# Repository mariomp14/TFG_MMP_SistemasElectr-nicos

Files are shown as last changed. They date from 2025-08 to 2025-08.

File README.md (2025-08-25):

# TFG_MMP_SistemasElectrónicos
Este repositorio fue creado como complemento de mi TFG para compartir:

### 1. **Firmware/**
Contiene el código fuente desarrollado:
- Programas escritos en C/C++.  
- Configuraciones y bibliotecas necesarias (CMake, scripts, etc.).

### 2. **PCBs/**
Incluye todos los archivos relacionados con el diseño y fabricación de la placa:
- `esquemas/`: diagramas eléctricos en formato `.sch` (KiCad).
- `diseño/`: los diseños en `.kicad_pcb`, `.pro`, `.kicad_sch`.
- `gerbers/`: los archivos estándares para fabricación.
- `pick_and_place/`: archivos `.csv` o `.pos` con coordenadas de colocación de componentes.

---

##  ¿Cómo usar este repositorio?

1. **Firmware**:
   - Clona el repositorio.
   - Ingresa al directorio `Firmware`.
   - Entiende el código y utilizalo en tu microcontrolador de Espressif!

2. **PCBs**:
   - Abre el diseño en KiCad.
   - Revisa esquemáticos y layout.
   - Si deseas fabricar, usa los Gerbers y el archivo de taladrado.

---

##  Contribuye

¿Quieres colaborar o revisar el proyecto?  
— Si deseas utilizar algún recurso, contrinuir mejoras o discutir ideas, **abre un issue** o envía un **Pull Request**. ¡Toda ayuda es bien recibida!

---

¡Gracias por explorar mi trabajo!  
— Mario (mariomp14)

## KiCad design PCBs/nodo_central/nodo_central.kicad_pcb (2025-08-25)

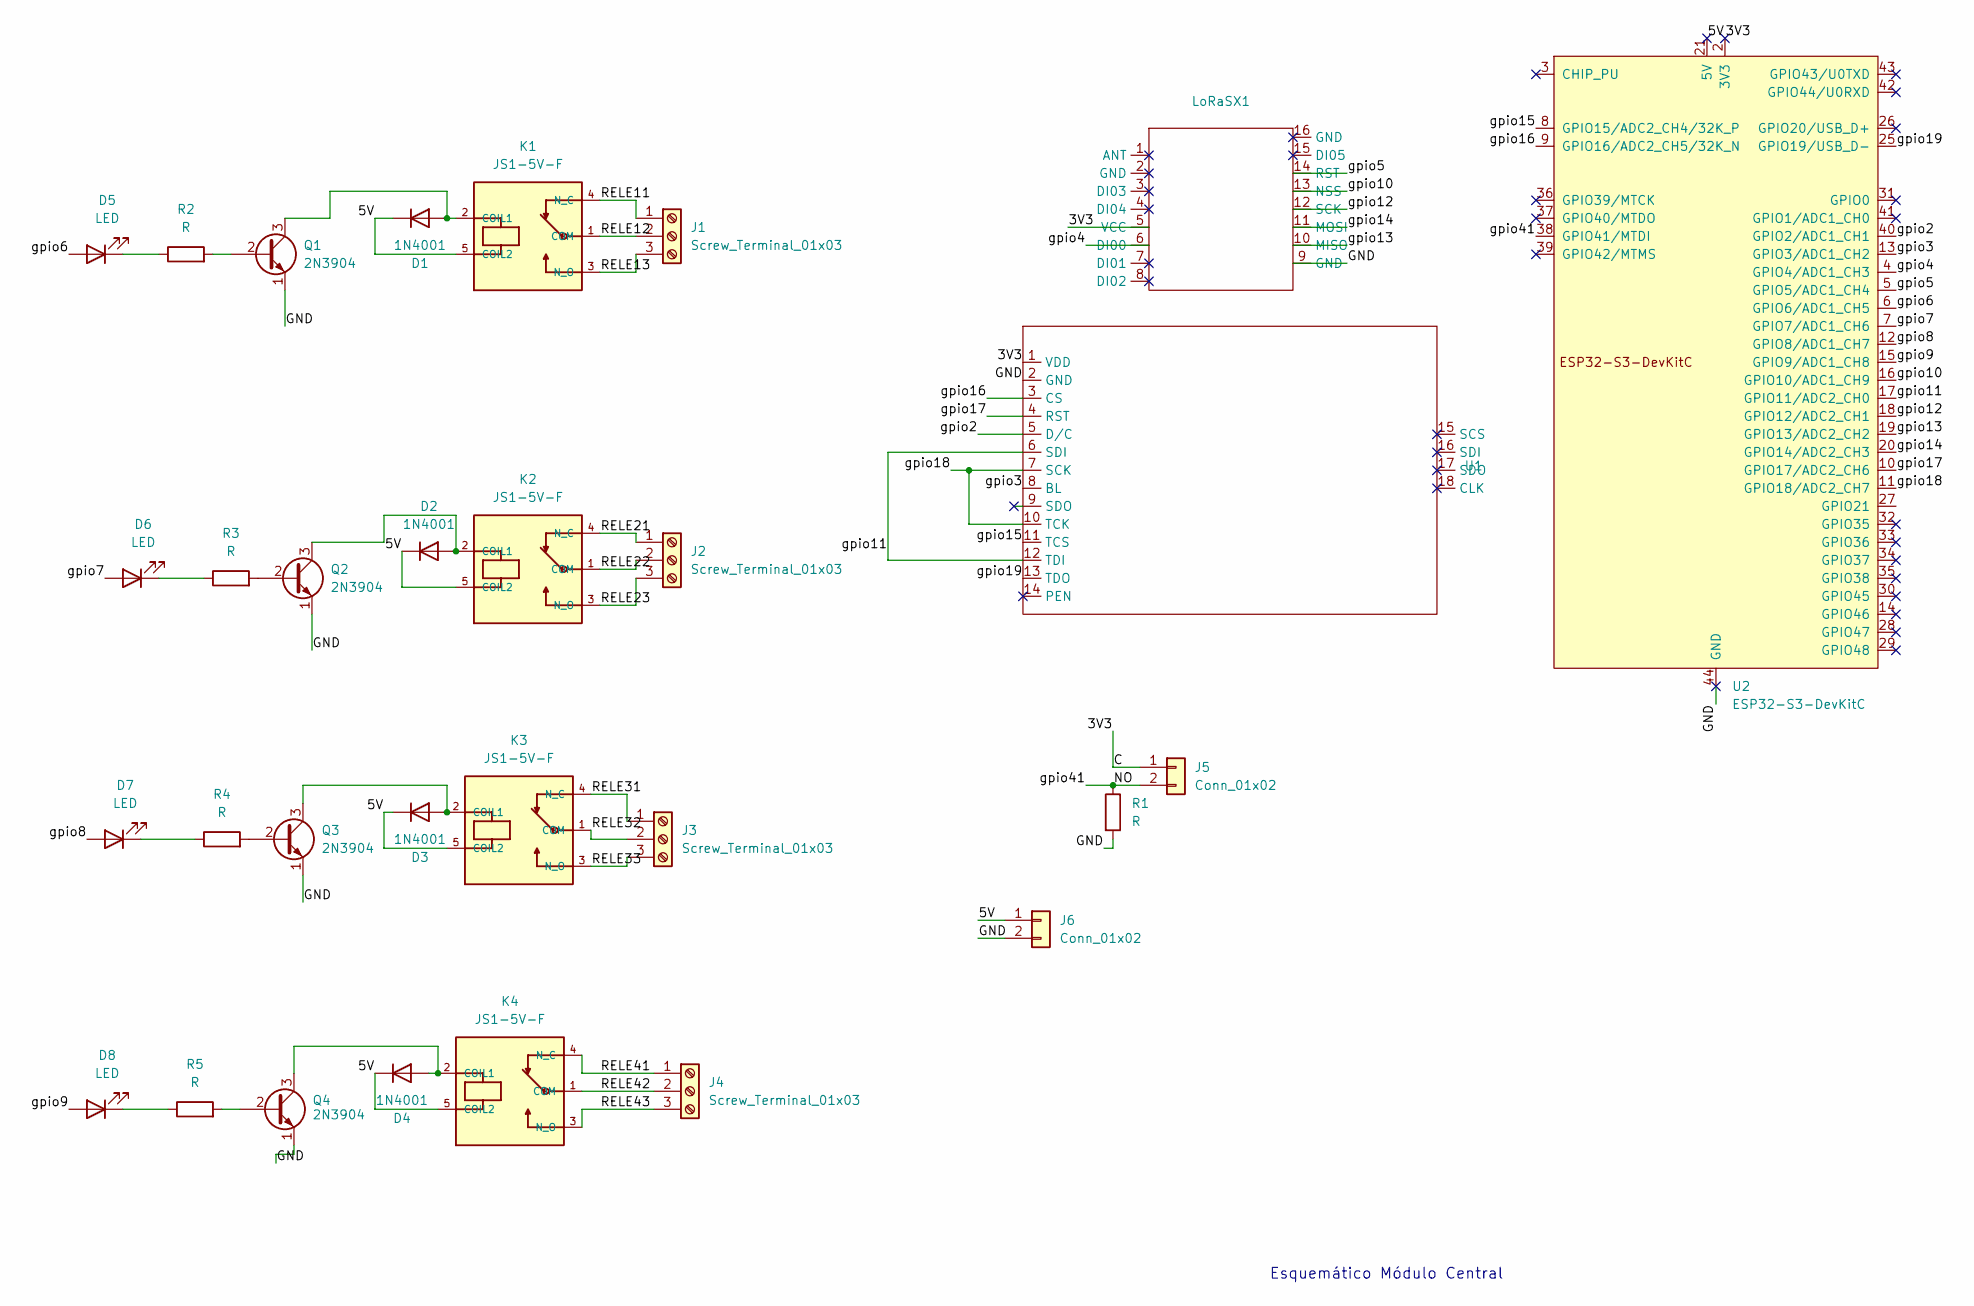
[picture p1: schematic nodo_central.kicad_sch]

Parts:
D1, D2, D3, D4: 1N4001; D_DO-41_SOD81_P10.16mm_Horizontal
D5, D6, D7, D8: LED; LED_D5.0mm
J1, J2, J3, J4: Screw_Terminal_01x03; TerminalBlock_bornier-3_P5.08mm
J5, J6: Conn_01x02; PinHeader_1x02_P2.54mm_Vertical
K1, K2, K3, K4: JS1-5V-F; RELAY_JS1-5V-F; PARTREV N/A
LoRaSX1: XCVR_RFM95W-868S2
Q1, Q2, Q3, Q4: 2N3904; TO-92_Inline_Wide
R1, R2, R3, R4, R5: R; R_Axial_DIN0207_L6.3mm_D2.5mm_P7.62mm_Horizontal
U1: ILI9488
U2: ESP32-S3-DevKitC

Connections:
/3V3: J5.1, LoRaSX1.5 (VCC), U1.1 (VDD), U2.1 (3V3), U2.2 (3V3)
/5V: D1.1 (K), D2.1 (K), D3.1 (K), D4.1 (K), J6.1, K1.5 (COIL2), K2.5 (COIL2), K3.5 (COIL2), K4.5 (COIL2), U2.21 (5V)
/GND: J6.2, LoRaSX1.9 (GND), Q1.1 (E), Q2.1 (E), Q3.1 (E), Q4.1 (E), R1.2, U1.2 (GND), U2.22 (GND), U2.23 (GND), U2.24 (GND), U2.44 (GND)
/NO: J5.2, R1.1, U2.38 (GPIO41/MTDI)
/RELE11: J1.1, K1.4 (N_C)
/RELE12: J1.2, K1.1 (COM)
/RELE13: J1.3, K1.3 (N_O)
/RELE21: J2.1, K2.4 (N_C)
/RELE22: J2.2, K2.1 (COM)
/RELE23: J2.3, K2.3 (N_O)
/RELE31: J3.1, K3.4 (N_C)
/RELE32: J3.2, K3.1 (COM)
/RELE33: J3.3, K3.3 (N_O)
/RELE41: J4.1, K4.4 (N_C)
/RELE42: J4.2, K4.1 (COM)
/RELE43: J4.3, K4.3 (N_O)
/gpio2: U1.5 (D/C), U2.40 (GPIO2/ADC1_CH1)
/gpio3: U1.8 (BL), U2.13 (GPIO3/ADC1_CH2)
/gpio4: LoRaSX1.6 (DI00), U2.4 (GPIO4/ADC1_CH3)
/gpio5: LoRaSX1.14 (RST), U2.5 (GPIO5/ADC1_CH4)
/gpio6: D5.2 (A), U2.6 (GPIO6/ADC1_CH5)
/gpio7: D6.2 (A), U2.7 (GPIO7/ADC1_CH6)
/gpio8: D7.2 (A), U2.12 (GPIO8/ADC1_CH7)
/gpio9: D8.2 (A), U2.15 (GPIO9/ADC1_CH8)
/gpio10: LoRaSX1.13 (NSS), U2.16 (GPIO10/ADC1_CH9)
/gpio11: U1.6 (SDI), U1.12 (TDI), U2.17 (GPIO11/ADC2_CH0)
/gpio12: LoRaSX1.12 (SCK), U2.18 (GPIO12/ADC2_CH1)
/gpio13: LoRaSX1.10 (MISO), U2.19 (GPIO13/ADC2_CH2)
/gpio14: LoRaSX1.11 (MOSI), U2.20 (GPIO14/ADC2_CH3)
/gpio15: U1.11 (TCS), U2.8 (GPIO15/ADC2_CH4/32K_P)
/gpio16: U1.3 (CS), U2.9 (GPIO16/ADC2_CH5/32K_N)
/gpio17: U1.4 (RST), U2.10 (GPIO17/ADC2_CH6)
/gpio18: U1.7 (SCK), U1.10 (TCK), U2.11 (GPIO18/ADC2_CH7)
/gpio19: U1.13 (TDO), U2.25 (GPIO19/USB_D-)
unnamed: D1.2 (A), K1.2 (COIL1), Q1.3 (C)
unnamed: D2.2 (A), K2.2 (COIL1), Q2.3 (C)
unnamed: D3.2 (A), K3.2 (COIL1), Q3.3 (C)
unnamed: D4.2 (A), K4.2 (COIL1), Q4.3 (C)
unnamed: D5.1 (K), R2.1
unnamed: D6.1 (K), R3.1
unnamed: D7.1 (K), R4.1
unnamed: D8.1 (K), R5.1
unnamed: Q1.2 (B), R2.2
unnamed: Q2.2 (B), R3.2
unnamed: Q3.2 (B), R4.2
unnamed: Q4.2 (B), R5.2

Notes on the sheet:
Esquemático Módulo Central

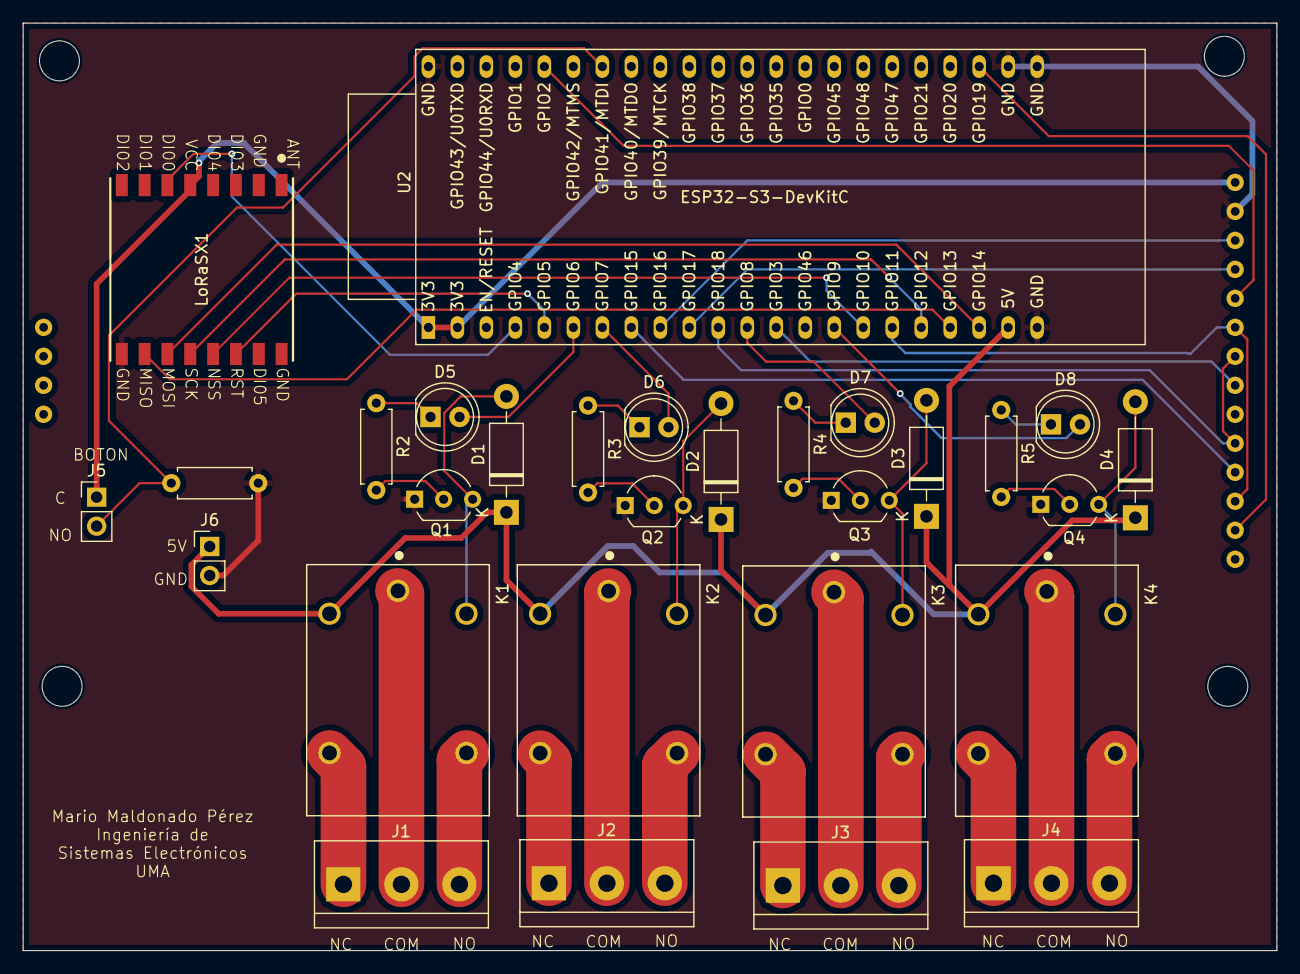
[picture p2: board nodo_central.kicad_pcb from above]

Board: 2 copper layers, 109.8 x 81.3 mm, 30 parts (1 on the bottom side), 46 nets.

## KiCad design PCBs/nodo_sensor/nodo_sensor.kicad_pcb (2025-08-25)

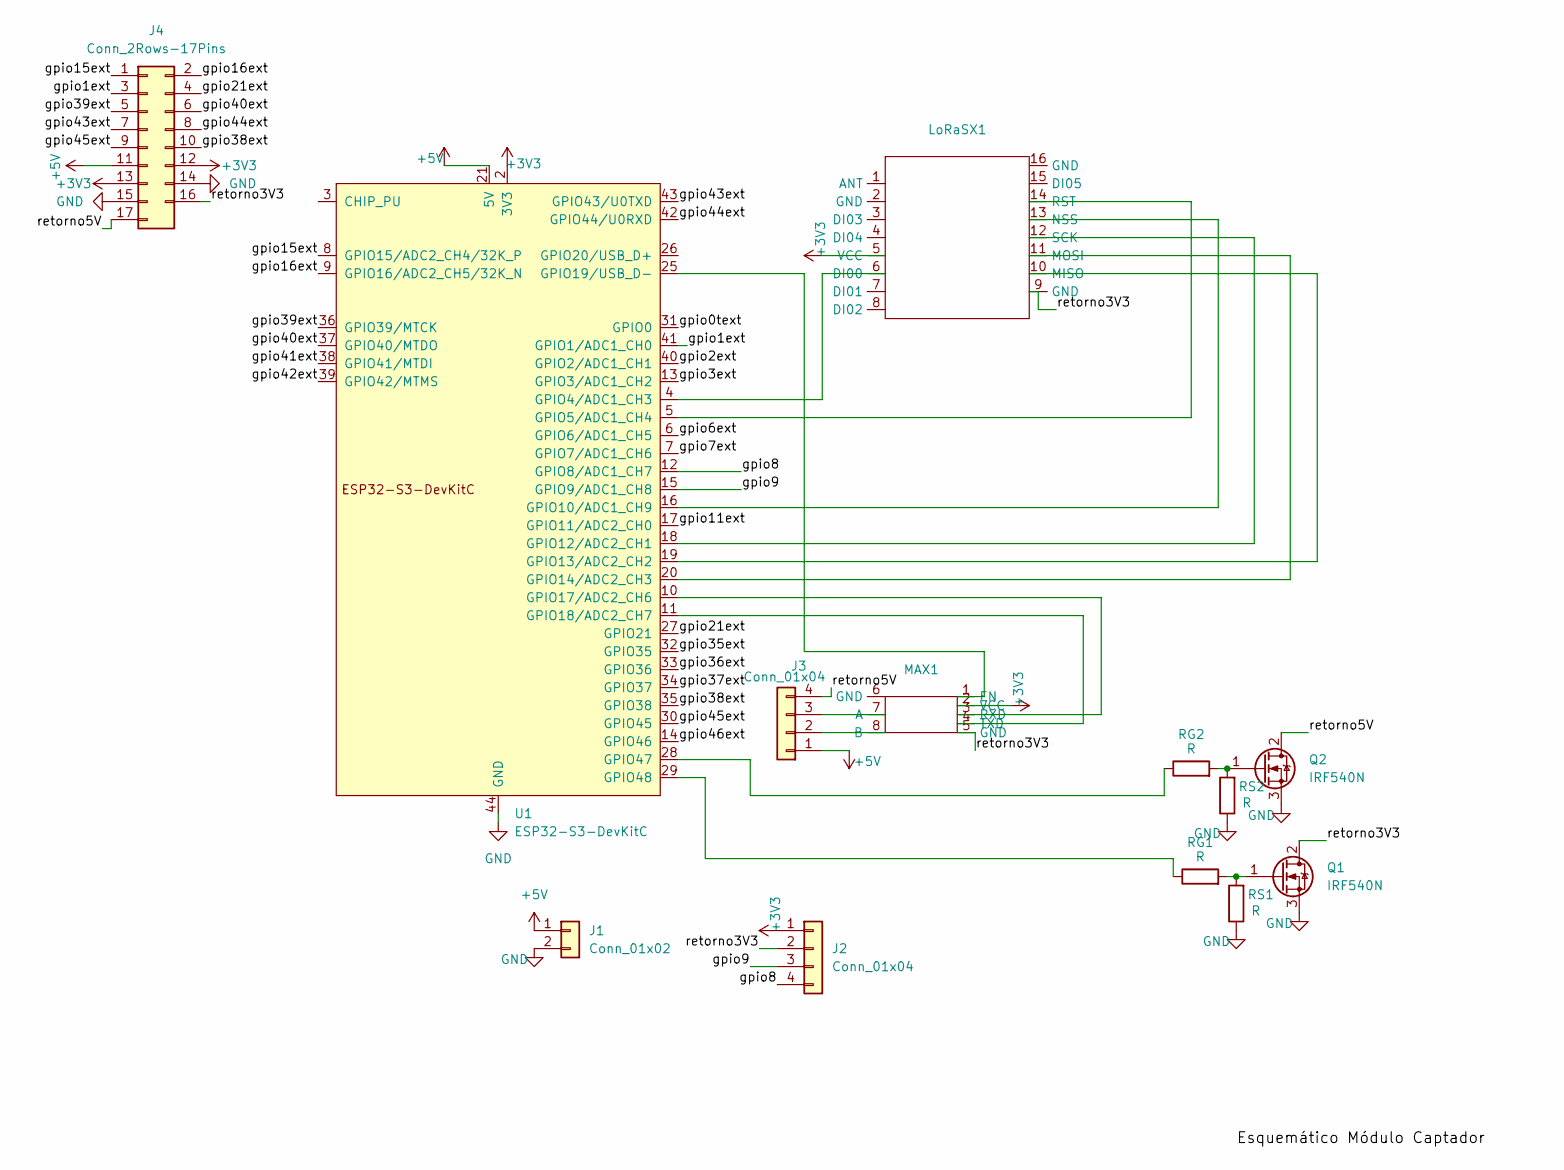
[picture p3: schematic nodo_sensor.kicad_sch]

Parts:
J1: Conn_01x02; PinHeader_1x02_P2.54mm_Vertical
J2: Conn_01x04; PinHeader_1x04_P2.54mm_Vertical_Humedad
J3: Conn_01x04; PinHeader_1x04_P2.54mm_Vertical_Suelo
J4: Conn_2Rows-17Pins; PinHeader_2x09_P2.54mm_Vertical
LoRaSX1: XCVR_RFM95W-868S2
MAX1: MAX3485
Q1, Q2: IRF540N; TO-220-3_Vertical
RG1, RG2: R; R_Axial_DIN0207_L6.3mm_D2.5mm_P7.62mm_Horizontal
RS1, RS2: R; R_Axial_DIN0207_L6.3mm_D2.5mm_P7.62mm_Horizontal
U1: ESP32-S3-DevKitC

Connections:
+3V3: J2.1, J4.12, J4.13, LoRaSX1.5 (VCC), MAX1.2 (VCC), U1.1 (3V3), U1.2 (3V3)
+5V: J1.1, J3.1, J4.11, U1.21 (5V)
/gpio0text: U1.31 (GPIO0)
/gpio1ext: J4.3, U1.41 (GPIO1/ADC1_CH0)
/gpio2ext: U1.40 (GPIO2/ADC1_CH1)
/gpio3ext: U1.13 (GPIO3/ADC1_CH2)
/gpio6ext: U1.6 (GPIO6/ADC1_CH5)
/gpio7ext: U1.7 (GPIO7/ADC1_CH6)
/gpio8: J2.4, U1.12 (GPIO8/ADC1_CH7)
/gpio9: J2.3, U1.15 (GPIO9/ADC1_CH8)
/gpio11ext: U1.17 (GPIO11/ADC2_CH0)
/gpio15ext: J4.1 (gpio15), U1.8 (GPIO15/ADC2_CH4/32K_P)
/gpio16ext: J4.2, U1.9 (GPIO16/ADC2_CH5/32K_N)
/gpio21ext: J4.4, U1.27 (GPIO21)
/gpio35ext: U1.32 (GPIO35)
/gpio36ext: U1.33 (GPIO36)
/gpio37ext: U1.34 (GPIO37)
/gpio38ext: J4.10, U1.35 (GPIO38)
/gpio39ext: J4.5, U1.36 (GPIO39/MTCK)
/gpio40ext: J4.6, U1.37 (GPIO40/MTDO)
/gpio41ext: U1.38 (GPIO41/MTDI)
/gpio42ext: U1.39 (GPIO42/MTMS)
/gpio43ext: J4.7, U1.43 (GPIO43/U0TXD)
/gpio44ext: J4.8, U1.42 (GPIO44/U0RXD)
/gpio45ext: J4.9, U1.30 (GPIO45)
/gpio46ext: U1.14 (GPIO46)
/retorno3V3: J2.2, J4.16, LoRaSX1.9 (GND), MAX1.5 (GND), Q1.2 (D)
/retorno5V: J3.4, J4.17, Q2.2 (D)
GND: J1.2, J4.14, J4.15, Q1.3 (S), Q2.3 (S), RS1.1, RS2.1, U1.22 (GND), U1.23 (GND), U1.24 (GND), U1.44 (GND)
unnamed: J3.2, MAX1.8 (B)
unnamed: J3.3, MAX1.7 (A)
unnamed: LoRaSX1.6 (DI00), U1.4 (GPIO4/ADC1_CH3)
unnamed: LoRaSX1.10 (MISO), U1.19 (GPIO13/ADC2_CH2)
unnamed: LoRaSX1.11 (MOSI), U1.20 (GPIO14/ADC2_CH3)
unnamed: LoRaSX1.13 (NSS), U1.16 (GPIO10/ADC1_CH9)
unnamed: LoRaSX1.14 (RST), U1.5 (GPIO5/ADC1_CH4)
unnamed: LoRaSX1.12 (SCK), U1.18 (GPIO12/ADC2_CH1)
unnamed: MAX1.1 (EN), U1.25 (GPIO19/USB_D-)
unnamed: MAX1.3 (RXD), U1.10 (GPIO17/ADC2_CH6)
unnamed: MAX1.4 (TXD), U1.11 (GPIO18/ADC2_CH7)
unnamed: Q1.1 (G), RG1.2, RS1.2
unnamed: Q2.1 (G), RG2.2, RS2.2
unnamed: RG2.1, U1.28 (GPIO47)
unnamed: RG1.1, U1.29 (GPIO48)

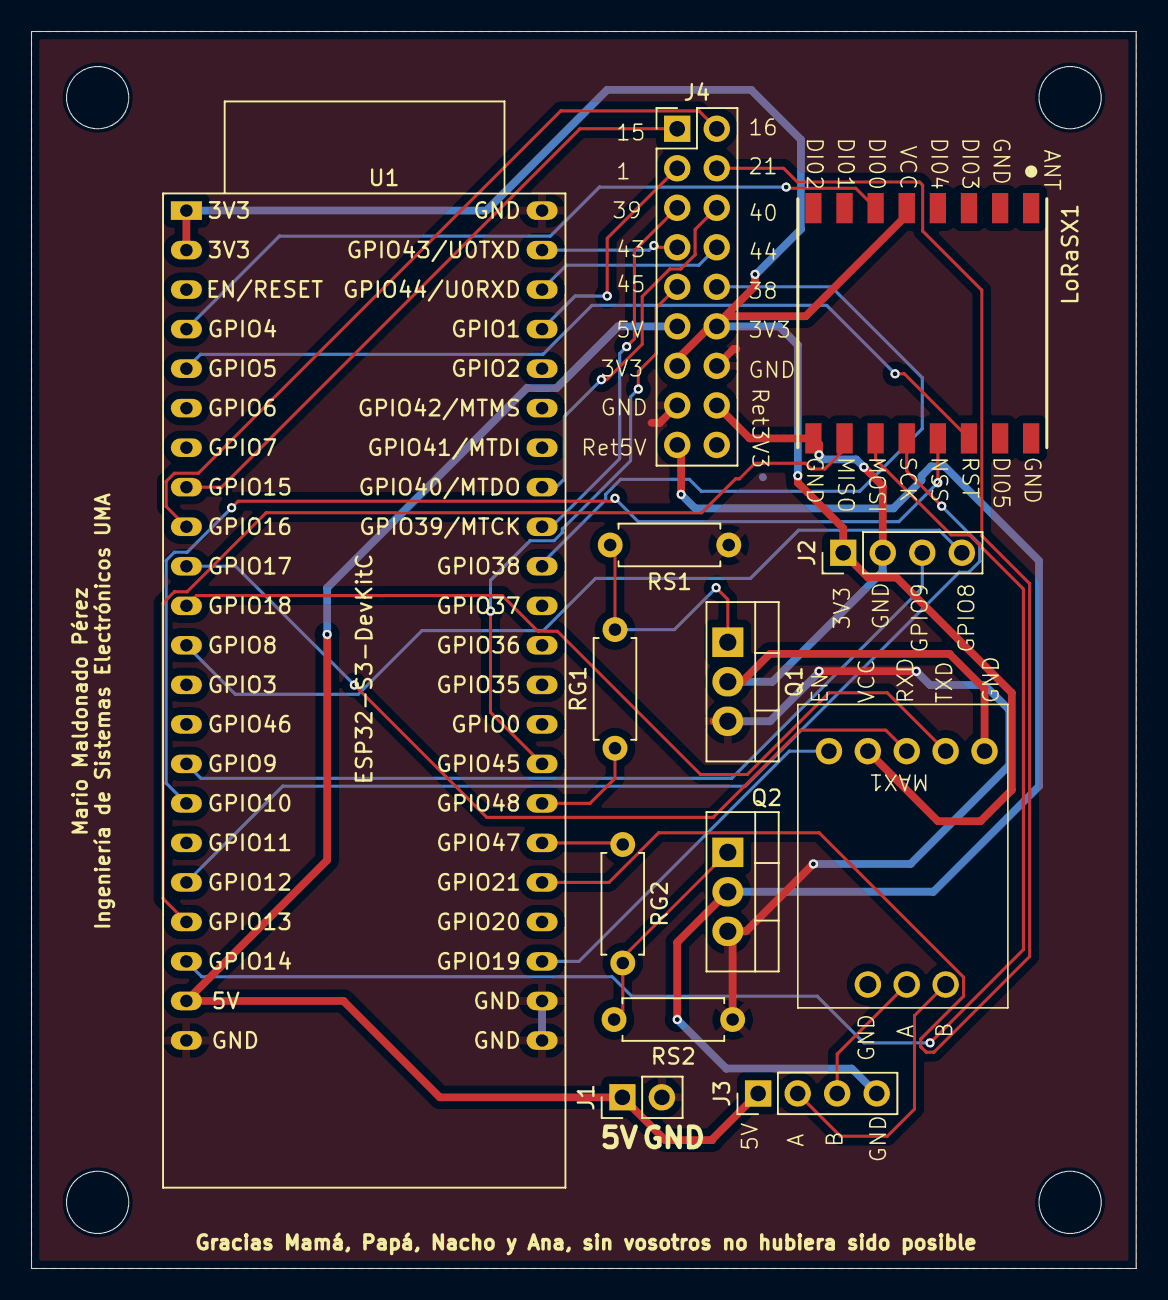
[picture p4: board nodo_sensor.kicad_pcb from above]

Board: 2 copper layers, 71.0 x 79.5 mm, 13 parts (0 on the bottom side), 32 nets.

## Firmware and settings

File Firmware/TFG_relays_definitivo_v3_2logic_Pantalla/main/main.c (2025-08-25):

#include "LoRa.h"
#include "esp_netif.h"
#include "freertos/FreeRTOSConfig.h"
#include "freertos/portmacro.h"
#include "sht40.h"
#include "driver/gpio.h"
#include "esp_err.h"
//#include "freertos/projdefs.h"
#include "hal/gpio_types.h"
#include <stdint.h>
#include <stdio.h>
#include <stdbool.h>
#include <string.h>
#include <unistd.h>

#include "freertos/FreeRTOS.h"
#include "freertos/task.h"
#include "esp_log.h"
#include "string.h"
#include "freertos/timers.h"
#include "esp_sleep.h"

#include "nvs_flash.h"
#include "mqtt_client.h"
#include "my_mqtt/include/my_mqtt.h"
#include "my_wifi/include/my_wifi.h"

#include "screen.h"
#include "ui.h"
#include <math.h>  // Para la función exp()

static const char *TAG = "LoRa_App";
static void safe_update_labels(void *param);
 
#define RELAY_1 GPIO_NUM_6
#define RELAY_2 GPIO_NUM_7
#define RELAY_3 GPIO_NUM_8
#define RELAY_4 GPIO_NUM_9
//Mecanismos de freeRTOS
static TaskHandle_t manejador_tarea_relays = NULL; 
static TaskHandle_t manejador_tarea_receiver = NULL; 
static QueueHandle_t lora_queue;  // Cola para almacenar los mensajes LoRa
static QueueHandle_t myQueueSet;
static SemaphoreHandle_t lora_semaphore;  // Semáforo para manejar la interrupción
static SemaphoreHandle_t security_semaphore_Sector1; 
static SemaphoreHandle_t security_semaphore_Sector2; 
SemaphoreHandle_t systemReadySemaphore;
TimerHandle_t timer_security_Sector1 = NULL; 
TimerHandle_t timer_security_Sector2 = NULL; 

QueueHandle_t cola_consignas;


RTC_DATA_ATTR volatile uint16_t light_sleep_time = 210;// 3 minutos y medio																																																
RTC_DATA_ATTR volatile uint32_t time_security_s = 180;
RTC_DATA_ATTR volatile uint16_t	convert_ms = 1000;

uint8_t MasterNode = 0xFF;//Nodo que controla la nebulización
uint8_t Node1 = 0xBB;
uint8_t Node2 = 0xAA;

#define BOTON_GPIO GPIO_NUM_41


//Funciones y tareas
static portTASK_FUNCTION(RELAYS, pvParameters);
static portTASK_FUNCTION(RECEIVER, pvParameters);
void configure_send_ack(uint8_t Node);
void setup_interrupt(void);
void procesar_buffer(uint8_t *buf);
static void  gpio_isr_handler(void *arg);
void CONSIGNMENTS(void *param);
uint8_t calcular_dpv(float temperatura, float humedad_relativa, uint8_t sector);
int automatismo_desactivado(void);
void actualizar_label_async(lv_obj_t *label, const char *nuevo_texto);
void inicializar_nvs_por_defecto();

 DatoLVGLtemporal temp_S1 = {0};  
 DatoLVGLtemporal hum_S1 = {0}; 
 DatoLVGLtemporal temp_S2 = {0}; 
 DatoLVGLtemporal hum_S2 = {0}; 
 DatoLVGLtemporal temp_suelo = {0}; 
 DatoLVGLtemporal hum_suelo = {0}; 
 DatoLVGLtemporal cond_suelo = {0}; 
 DatoLVGLtemporal ph_suelo = {0}; 
 DatoLVGLtemporal DPVS1 = {0};
 DatoLVGLtemporal DPVS2 = {0};
 DatoLVGLtemporal DPVminS1 = {0};
 DatoLVGLtemporal DPVminS2 = {0};
 DatoLVGLtemporal DPVmaxS1 = {0};
 DatoLVGLtemporal DPVmaxS2 = {0};
 DatoLVGLbooltemporal Rele1 = {0}; 
 DatoLVGLbooltemporal Rele2= {0}; 
 DatoLVGLbooltemporal estado_automatismo= {0}; 

void IRAM_ATTR boton_isr_handler(void* arg) {
    BaseType_t xHigherPriorityTaskWoken = pdFALSE;
    xSemaphoreGiveFromISR(semaforo_activar_timer_screen, &xHigherPriorityTaskWoken);
    if (xHigherPriorityTaskWoken) {
        portYIELD_FROM_ISR();
    }
}



void app_main(void)
{
	
	systemReadySemaphore = xSemaphoreCreateBinary();  // Crear el semáforo global
	
	//WIFI e MQTT//
	esp_log_level_set("wifi", ESP_LOG_VERBOSE);//Habilita los logs detallados de Wi-Fi para ver mensajes de error:
	 									//Poner un comando desde mqtt para eliminar la flash?
	//nvs_flash_erase(); 					//Solo para pruebas, eliminar?!->borra memoria NVS. Ojo si pongo esto no tendria sentido guardarlo en la memoria volátil no?
    ESP_ERROR_CHECK(nvs_flash_init());  //Se usa para guardar datos en memoria no volátil, como credenciales WiFi, configuraciones o tokens de acceso.
    inicializar_nvs_por_defecto();  // para guardar los valores de dpv max y min y si esta o no desactivado el automatismo
    esp_netif_init();					//inicializa la pila de red, para poder usar wifi
    esp_event_loop_create_default();	//crea e inicializa el bucle de eventos predeterminado en esp-idf (wifi,bluetooth...)
    wifi_connect_sta();
	

    ESP_LOGI("MAIN", "Esperando WiFi y MQTT...");
    xSemaphoreTake(systemReadySemaphore, portMAX_DELAY);
    ESP_LOGI("MAIN", "WiFi y MQTT conectados. Continuando ejecución...");
    
	/////////////////////////
	
    // Inicialización de LoRa
    ESP_LOGI(TAG, "Inicializando LoRa...");
    if (!lora_init()) {
        ESP_LOGE(TAG, "Error al inicializar LoRa");
        return;
    }
    
    // Configurar el pin de interrupción DIO0
    gpio_config_t io_conf = {};
    io_conf.intr_type = GPIO_INTR_POSEDGE;  // Interrupción en flanco de subida
    io_conf.mode = GPIO_MODE_INPUT;
    io_conf.pin_bit_mask = (1ULL << LORA_DIO0_PIN);
    io_conf.pull_down_en = GPIO_PULLDOWN_DISABLE;
    io_conf.pull_up_en = GPIO_PULLUP_ENABLE;
    gpio_config(&io_conf);

    // Instalar ISR y registrar el manejador de interrupción
    gpio_install_isr_service(0);  
    gpio_isr_handler_add(LORA_DIO0_PIN, gpio_isr_handler, NULL);
    
    /////////////////////////////////////////////////
    //Timer de seguridad de 3.5mins
    timer_security_Sector1 = xTimerCreate("TimerWakeup1", pdMS_TO_TICKS(210000), pdFALSE, NULL, parpadeoAsimCallbackRelay1);
	timer_security_Sector2 = xTimerCreate("TimerWakeup2", pdMS_TO_TICKS(210000), pdFALSE, NULL, parpadeoAsimCallbackRelay2);
    // Configuración básica
    ESP_LOGI(TAG, "Configurando LoRa...");
    lora_set_frequency(868E6);       // Configurar frecuencia (por ejemplo, 868 MHz)
    ESP_LOGI(TAG, "Frecuencia configurada a 868 MHz");
    
    lora_set_tx_power(10);           // Configurar potencia de transmisión
    ESP_LOGI(TAG, "Potencia de transmision configurada a 10 dBm");
    

    ESP_LOGI(TAG, "CRC habilitado para asegurar la integridad de los datos");
	
	//MIRAR que otros parámetros de la comunicación LoRa y de la trama se pueden modificar*
	
    
    lora_receive();//Pongo LoRa en modo recepción
	gpio_set_direction(RELAY_1, GPIO_MODE_OUTPUT); // Configurar pin  como salida para el relé 1
	gpio_set_direction(RELAY_2, GPIO_MODE_OUTPUT); // Configurar pin  como salida para el relé 2
    gpio_set_direction(RELAY_3, GPIO_MODE_OUTPUT); // Configurar pin  como salida para el relé 2
  	lora_enable_crc();

	// Crear la cola (10 mensajes de 6 bytes cada uno)
	//La FIFO del módulo LoRa tiene 256 bytes, así que en tamaño de la cola máximo
    //podría ser 256bytes/tamaño del paquete, pero lo pongo de tamaño 10 para empezar
    lora_queue = xQueueCreate(10, sizeof(char) * 14);// ya que recibo 14 bytes comomaximo del Nodo2
    if (lora_queue == NULL) 
    {
        ESP_LOGE(TAG, "Error al crear la cola");
        while (1);
    }
    mqtt_queue = xQueueCreate(10, sizeof(mqtt_message_t));  // Crear la cola con 10 mensajes
    
    if (mqtt_queue == NULL) 
    {
        ESP_LOGE(TAG, "Error al crear la cola");
        while (1);
    }

    // Crear semáforo binario
    lora_semaphore = xSemaphoreCreateBinary();
    security_semaphore_Sector1 = xSemaphoreCreateBinary();
    security_semaphore_Sector2 = xSemaphoreCreateBinary();
    mutexUmbrales = xSemaphoreCreateMutex(); // Crear el mutex
    // Crear un QueueSet con espacio para ambos
    myQueueSet = xQueueCreateSet(10 + 2);  // Máximo de elementos en la cola + semáforos
    
    // Agregar la cola y el semáforo al QueueSet
    xQueueAddToSet(lora_queue, myQueueSet);
    xQueueAddToSet(security_semaphore_Sector1, myQueueSet);
    xQueueAddToSet(security_semaphore_Sector2, myQueueSet);
    
    //PANTALLA
    screen_mutex = xSemaphoreCreateMutex();
	semaforo_activar_timer_screen= xSemaphoreCreateBinary();
	
	gpio_set_direction(TFT_BL, GPIO_MODE_OUTPUT);
	gpio_set_level(TFT_BL, 0);  // Inicia apagado
    gpio_config_t io_conf2 = {
        .pin_bit_mask = 1ULL << BOTON_GPIO,
        .mode = GPIO_MODE_INPUT,
        .pull_up_en = GPIO_PULLUP_ENABLE,
        .intr_type = GPIO_INTR_NEGEDGE
    };
    gpio_config(&io_conf2);
    gpio_install_isr_service(0);
    gpio_isr_handler_add(BOTON_GPIO, boton_isr_handler, NULL);
	
	apagar_screen_timer = xTimerCreate(
    "apagar_timer",
    pdMS_TO_TICKS(2 * 60 * 1000),  // 2 minutos
    pdFALSE,
    NULL,
    apagar_pantalla  // nueva función callback
	);
	 //Tarea y cola que gestionan las consignas recibidas por pantalla (y por mqtt???)
	cola_consignas = xQueueCreate(10, sizeof(ConsignasLVGL));
	
	//
	timerSector1 = xTimerCreate("ParpadeoAsim1", tiempo_off, pdFALSE, NULL, parpadeoAsimCallbackRelay1);
	timerSector2 = xTimerCreate("ParpadeoAsim2", tiempo_off, pdFALSE, NULL, parpadeoAsimCallbackRelay2);
	estado_Rele_Sector1 = 0;//se inicializan apagados!
	estado_Rele_Sector1 = 0;
	// 
	xReleMutex = xSemaphoreCreateMutex();
	xTaskCreate(CONSIGNMENTS, "TareaConsignas", 4096, NULL, 1, NULL);
 	//Tarea que gestiona los relés y las recepciones LoRa
 	//tambien puedo utilizar x TaskCreatePinnedToCore...
  	xTaskCreate(RELAYS, "SendMsgTask", 4096, NULL, 1, &manejador_tarea_relays);
	xTaskCreate(RECEIVER, "SendMsgTask", 4096, NULL, 1, &manejador_tarea_receiver);
   	xTaskCreate(MQTT, "MQTT", 4096, NULL, 5, NULL);
   	//Tareas pantalla
	xTaskCreatePinnedToCore(
                    SCREEN,
                    "screen_task",
                    12288,//8192
                    NULL,
                    5,
                    &screen_task_handle,
                    1
                );
    xTaskCreate(SCREEN_ON_OFF, "tarea_control_pantalla", 4096, NULL, 2, NULL);
   	//vTaskStartScheduler();	//No es necesario llamarlo explicitamente en el esp32

}

void vTimerAckCallback_Sector1(TimerHandle_t xTimer) {
    ESP_LOGI(TAG, "Temporizador Seguridad Sector 1 activado!");
    xSemaphoreGive(security_semaphore_Sector1);
}

void vTimerAckCallback_Sector2(TimerHandle_t xTimer) {
    ESP_LOGI(TAG, "Temporizador Seguridad Sector 2 activado!");
    xSemaphoreGive(security_semaphore_Sector2);
}

/* Light Sleep suspende la CPU y puede afectar la conexión TCP
Aunque WiFi se mantiene activo en "Modem Sleep", la conexión TCP/MQTT podría cerrarse si no responde a tiempo.
Esto sucede porque MQTT usa una conexión TCP persistente, y si la conexión se interrumpe por Light Sleep,
 el ESP32 intentará reconectar automáticamente.
 void sleep_now(void) -> Por tanto he eliminado esta función
*/

void CONSIGNMENTS(void *param) {//tarea consginas desde pantalla?
    ConsignasLVGL evento;
    nvs_handle_t handle;
    esp_err_t err;

    while (1) {
        if (xQueueReceive(cola_consignas, &evento, portMAX_DELAY)) {
            // Abrimos el espacio "consignas" en la NVS
            err = nvs_open("storage", NVS_READWRITE, &handle);
            if (err != ESP_OK) {
                printf("Error abriendo NVS: %s\n", esp_err_to_name(err));
                continue;
            }

            switch (evento.tipo) {
                case EVENTO_DPV_MINS1:
                    err = nvs_set_i32(handle, "DPVMinS1", evento.valor);
                    break;

                case EVENTO_DPV_MAXS1:
                    err = nvs_set_i32(handle, "DPVMaxS1", evento.valor);
                    break;

                case EVENTO_DPV_MINS2:
                    err = nvs_set_i32(handle, "DPVMinS2", evento.valor);
                    break;

                case EVENTO_DPV_MAXS2:
                    err = nvs_set_i32(handle, "DPVMaxS2", evento.valor);
                    break;

                case EVENTO_DESACTIVAR_AUTOMATISMO:
                    err = nvs_set_i32(handle, "AutoOFF", evento.valor);  // 0 o 1
                    break;

                case EVENTO_NEBULIZARS1:
                   // err = nvs_set_i32(handle, "NebS1", evento.valor);
                    //gpio_set_level(RELAY_1, (evento.valor == 1) ? 0 : 1);
                    gpio_set_level(RELAY_3, evento.valor);
                    
                    if(evento.valor == 0)
                    { 
						xTimerStop(timerSector1, portMAX_DELAY);
						gpio_set_level(RELAY_1, 0);  // apagar relé,por si justo en el momento de parar el timer estaba encendido!-> (por el blink)
                  		if (xSemaphoreTake(xReleMutex, portMAX_DELAY)) {
                  		estado_Rele_Sector1 = 0;
                  		if(!estado_Rele_Sector2)
                  		{
							  gpio_set_level(RELAY_3, 0); //se apaga rele que controla flujo general del agua
						 }
                  		xSemaphoreGive(xReleMutex);
                  		}
                  		esp_mqtt_client_publish(client, "mariomp/f/activacionRele1", "OFF", 0, 1, 0);
                   	}
                   	else 
                   	{
						xTimerStart(timerSector1, portMAX_DELAY);
						if (xSemaphoreTake(xReleMutex, portMAX_DELAY)) {
                  		estado_Rele_Sector1 = 1;
                  		xSemaphoreGive(xReleMutex);
                  		}
                  		gpio_set_level(RELAY_3, 1);//general
						esp_mqtt_client_publish(client, "mariomp/f/activacionRele1", "ON", 0, 1, 0);
					}
                    break;

                case EVENTO_NEBULIZARS2:
                    //err = nvs_set_i32(handle, "NebS2", evento.valor);
                    //gpio_set_level(RELAY_2, (evento.valor == 1) ? 0 : 1);
                    gpio_set_level(RELAY_3, evento.valor);
                    
                     if(evento.valor == 0)
                    { 
						xTimerStop(timerSector2, portMAX_DELAY);
						gpio_set_level(RELAY_2, 0);  // apagar relé,por si justo en el momento de parar el timer estaba encendido!
                  		if (xSemaphoreTake(xReleMutex, portMAX_DELAY)) {
                  		estado_Rele_Sector2 = 0;
                  		if(!estado_Rele_Sector1)
                  		{
							  gpio_set_level(RELAY_3, 0); //se apaga rele que controla flujo general del agua
						 }
                  		xSemaphoreGive(xReleMutex);
                  		}
                  		esp_mqtt_client_publish(client, "mariomp/f/activacionRele2", "OFF", 0, 1, 0);
                   	}
                   	 else 
                   	{
						xTimerStart(timerSector2, portMAX_DELAY);
						if (xSemaphoreTake(xReleMutex, portMAX_DELAY)) {
                  		estado_Rele_Sector2 = 1;
                  		xSemaphoreGive(xReleMutex);
                  		}
                  		gpio_set_level(RELAY_3, 1);//general
						esp_mqtt_client_publish(client, "mariomp/f/activacionRele2", "ON", 0, 1, 0);
					}
                    break;

                default:
                    printf("Evento no reconocido: %d\n", evento.tipo);
                    err = ESP_ERR_INVALID_ARG;
                    break;
            }

            if (err == ESP_OK) {
                err = nvs_commit(handle);  // Importante: guarda los cambios en la Flash
                if (err != ESP_OK) {
                    printf("Error al hacer commit en NVS: %s\n", esp_err_to_name(err));
                }
            } else {
                printf("Error al guardar en NVS: %s\n", esp_err_to_name(err));
            }
			nvs_commit(handle);
            nvs_close(handle);  // Cierro el handle
        }
    }
}

//sirve ante posibles fallos de alimentacion o reinicios para guardar las consignas
//para realizar el automatismo (por ejemplo valores como la lectura de los sensores no 
//los guardo aqui ya que no son tan criticos)))
void inicializar_nvs_por_defecto() {
    nvs_handle_t handle;
    esp_err_t err;
//particion NSV definida en el archivo partitions.csv
    err = nvs_open("storage", NVS_READWRITE, &handle);
    if (err != ESP_OK) {
        ESP_LOGE("NVS", "Error al abrir NVS: %s", esp_err_to_name(err));
        return;
    }

    int32_t  valor ;
	float valor_float;
    // Verifica y establece valor por defecto si no existe
    if (nvs_get_i32(handle, "DPVMinS1", &valor) == ESP_ERR_NVS_NOT_FOUND) {
        nvs_set_i32(handle, "DPVMinS1", 10);  // 1.0 kPa
        valor = 10;
    }
	ESP_LOGW("DEBUG", "valorvvvvvvvvvvvvvvvvvvvvvvvvvvvvvvvvv = %ld", (long)valor);
	//Hago esto para que se muestr por la secreen física desde el arranque del sistema
	// y que concuerde las consginas que se ven por pantalla con las que utiliza el programa 
	//por dentro
	// Ahora convierto a float dividiendo
	valor_float = (float)valor / 10.0f;
	snprintf(DPVminS1.valor, SENSOR_STR_SIZE, "%.1f", valor_float);
    DPVminS1.valor[SENSOR_STR_SIZE - 1] = '\0';
    DPVminS1.actualizado = true;
    
    if (nvs_get_i32(handle, "DPVMaxS1", &valor) == ESP_ERR_NVS_NOT_FOUND) {
        nvs_set_i32(handle, "DPVMaxS1", 15);  // 1.5 kPa
        valor = 15;
    }
    
    valor_float = (float)valor / 10.0f;
	snprintf(DPVmaxS1.valor, SENSOR_STR_SIZE, "%.1f", valor_float);
    DPVmaxS1.valor[SENSOR_STR_SIZE - 1] = '\0';
    DPVmaxS1.actualizado = true;

    if (nvs_get_i32(handle, "DPVMinS2", &valor) == ESP_ERR_NVS_NOT_FOUND) {
        nvs_set_i32(handle, "DPVMinS2", 10);
        valor = 10;
    }
	
	valor_float = (float)valor / 10.0f;
	snprintf(DPVminS2.valor, SENSOR_STR_SIZE, "%.1f", valor_float);
    DPVminS2.valor[SENSOR_STR_SIZE - 1] = '\0';
    DPVminS2.actualizado = true;
    
    if (nvs_get_i32(handle, "DPVMaxS2", &valor) == ESP_ERR_NVS_NOT_FOUND) {
        nvs_set_i32(handle, "DPVMaxS2", 15);
        valor = 15;
    }
	
	valor_float = (float)valor / 10.0f;
	snprintf(DPVmaxS2.valor, SENSOR_STR_SIZE, "%.1f", valor_float);
    DPVmaxS2.valor[SENSOR_STR_SIZE - 1] = '\0';
    DPVmaxS2.actualizado = true;
    
    if (nvs_get_i32(handle, "AutoOFF", &valor) == ESP_ERR_NVS_NOT_FOUND) {
        nvs_set_i32(handle, "AutoOFF", 0);  // Automatismo activo por defecto
        valor = 0;
    }
	if(valor == 0)
    {
		estado_automatismo.estadoReles = false;
		estado_automatismo.actualizado = true;
	}
	else if(valor == 1)
	{
		estado_automatismo.estadoReles = true;
		estado_automatismo.actualizado = true;
	}

    nvs_commit(handle);
    nvs_close(handle);
}

esp_err_t comprobar_direcciones(uint8_t *buf)
{
	if(buf[0] == MasterNode && (buf[1] == Node1 || buf[1] == Node2))
		return ESP_OK;
		
	return ESP_FAIL;	
}

static portTASK_FUNCTION(RELAYS, pvParameters)
{
    int received_bytes = 0;//del nodo1 vendrian 6 y del nodo2 14
    uint8_t *received_msg;
    uint8_t node_id;
    QueueSetMemberHandle_t activatedHandle;
    while (1)
    {
        // Esperar un mensaje en la cola o que el semáforo sea liberado
        activatedHandle = xQueueSelectFromSet(myQueueSet, portMAX_DELAY);
        // if (eventosRELES & ACTUALIZAR_RELES)
        if (activatedHandle == lora_queue)
        {
            // leo mensaje
            ESP_LOGI(TAG, "Mensajes antes de recibir: %d", uxQueueMessagesWaiting(lora_queue));
            if (xQueueReceive(lora_queue, &received_msg, portMAX_DELAY) == pdPASS)
            {
                ESP_LOGI(TAG, "Cola recibida:");
            }
            
                // Detectar el nodo emisor por el segundo byte
             node_id = received_msg[1];
             received_bytes = 0;
             
            //ESP_LOGI(TAG, "Mensajes despues de recibir: %d", uxQueueMessagesWaiting(lora_queue));
            if (node_id == Node1) {
                    received_bytes = 6;   // Nodo1 (ambiente)
            } else if (node_id == Node2) {
                    received_bytes = 14;  // Nodo2 (suelo + ambiente)
             } 
        
             
            for (int i = 0; i < received_bytes; i++)
            {
                ESP_LOGI(TAG, "Byte %d: 0x%02X", i, received_msg[i]); // Mostrar en formato hexadecimal
            }
			
			// Crear una copia local del mensaje antes de procesarlo
             //uint8_t local_msg[received_bytes];
             uint8_t local_msg[14];
             memcpy(local_msg, received_msg, received_bytes);
                    
            procesar_buffer(local_msg);
            
            // Solo liberar el mensaje si fue asignado dinámicamente
             if (received_msg != NULL)
              {
				  
                     free(received_msg);
                      received_msg = NULL;
              }
            //free(received_msg); // Libera la memoria después de procesar el mensaje
            // mando ack-> Consta de direcciones y variable preservada?
            // ojo solo puedo mandar ack si la otra tarea está inactiva?->Pensar
            //esto ya lo hago dentro de procesar_buffer
           // configure_send_ack(); // inecitablemente si haymuchas peticiones se perderá alguna al tener que enviar el ack_correspondiente
        }
        else if (activatedHandle == security_semaphore_Sector1)
        {
            // Apago relés por si estaban encendidos
            //gpio_set_level(RELAY_1, portMAX_DELAY); //
            xTimerStop(timerSector1, portMAX_DELAY);
			gpio_set_level(RELAY_1, 0);  // apagar relé,por si justo en el momento de parar el timer estaba encendido!
			if(xSemaphoreTake(xReleMutex, portMAX_DELAY))
			{
				estado_Rele_Sector1 = 0;
				if(!estado_Rele_Sector2)
				{
					gpio_set_level(RELAY_3, 0); // se apaga el general
				}
				xSemaphoreGive(xReleMutex);
			}

            esp_mqtt_client_publish(client, "mariomp/f/activacionRele1", "OFF", 0, 1, 0);
            ESP_LOGI(TAG, "Rele Sector1 desactivados:");
        }
        else // (activatedHandle == security_semaphore_Sector1)
        {
            xTimerStop(timerSector2, portMAX_DELAY);
			gpio_set_level(RELAY_2, 0);  // apagar relé,por si justo en el momento de parar el timer estaba encendido!(blink)
			if(xSemaphoreTake(xReleMutex, portMAX_DELAY))
			{
				estado_Rele_Sector2 = 0;
				if(!estado_Rele_Sector1)
				{
					gpio_set_level(RELAY_3, 0); // se apaga el general
				}
				xSemaphoreGive(xReleMutex);
			}
            esp_mqtt_client_publish(client, "mariomp/f/activacionRele2", "OFF", 0, 1, 0);
            ESP_LOGI(TAG, "Rele Sector2 desactivados:");
		}
    }
}
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

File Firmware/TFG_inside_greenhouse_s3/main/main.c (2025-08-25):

#include "LoRa.h"
#include "driver/gpio.h"
#include "esp_err.h"
#include "freertos/projdefs.h"
#include "hal/gpio_types.h"
#include "sht40.h"
#include <stdint.h>
#include <stdio.h>
#include <stdbool.h>
#include <string.h>
#include <unistd.h>
#include "freertos/FreeRTOS.h"
#include "freertos/task.h"
#include "esp_log.h"
#include "string.h"
#include "freertos/timers.h"
#include <esp_sleep.h>


//#include "esp_timer.h" //precision de microsegundos, no necesaria para mi aplicacion

static TimerHandle_t xTimerACK;
static TaskHandle_t manejador_tarea_ACK = NULL; // manejador de la tarea DEL ADC
static EventGroupHandle_t FlagsEventos;                 // flag de eventos
#define COMPROBAR_ACK 0x01                              //(1<<0) // 0x0001
#define REEQUERIR_ACK 0x02                              //(1<<1)// 0x0002
static int interval_ack = 10000;
static int timerACK_ID = 1;
static const char *TAG = "LoRa_App";
void configure_send_trama_lora(uint16_t raw_temperature, uint16_t raw_humidity);
esp_err_t static set_timer_ACK (void);
esp_err_t init_ISR_LoRa(void);
//static void IRAM_ATTR lora_on_dio0_rise(void* arg);
uint8_t MasterNode = 0xFF;//Nodo que controla la nebulización
uint8_t Node1 = 0xBB;

static portTASK_FUNCTION(GESTIONAR_ACK, pvParameters);
esp_err_t comprobar_ACK (uint8_t *buffer);
uint16_t raw_temperature; 
uint16_t raw_humidity;


#define uS_TO_S_FACTOR 1000000  // Conversión de segundos a microsegundos
#define TIME_TO_SLEEP 10         // Tiempo de sleep en segundos
    
void app_main(void)
{
    // Inicialización de LoRa
    ESP_LOGI(TAG, "Inicializando LoRa...");
    if (!lora_init()) {
        ESP_LOGE(TAG, "Error al inicializar LoRa");
        return;
    }
    
    // Configuración básica
    ESP_LOGI(TAG, "Configurando LoRa...");
    lora_set_frequency(868E6);       // Configurar frecuencia (por ejemplo, 868 MHz)
    ESP_LOGI(TAG, "Frecuencia configurada a 868 MHz");
    
    lora_set_tx_power(10);           // Configurar potencia de transmisión
    ESP_LOGI(TAG, "Potencia de transmision configurada a 10 dBm");
    

    ESP_LOGI(TAG, "CRC habilitado para asegurar la integridad de los datos");
	
    
    i2c_master_init_bus();
    i2c_master_init_handle( SHT40_I2C_ADDRESS);
    
    init_ISR_LoRa();
    lora_receive();//ojo-> esto no hace falta
 	//Tarea que gestiona el ACK
  	xTaskCreate(GESTIONAR_ACK, "SendMsgTask", 4096, NULL, 1, &manejador_tarea_ACK);
   
    FlagsEventos = xEventGroupCreate();
    if (FlagsEventos == NULL)
    {
     while (1)
      ;
    }

    // Configura GPIO48 como salida
    gpio_config_t io_conf = {
        .pin_bit_mask = (1ULL << GPIO_NUM_48), // Bitmask para GPIO4
        .mode = GPIO_MODE_OUTPUT,             // Modo salida
        .pull_up_en = GPIO_PULLUP_DISABLE,
        .pull_down_en = GPIO_PULLDOWN_DISABLE,
        .intr_type = GPIO_INTR_DISABLE
    };
    gpio_config(&io_conf);

    // Pone GPIO48 para alimentar sensor haciendo conmutar mosfet
    gpio_set_level(GPIO_NUM_48, 1);

	vTaskDelay(pdMS_TO_TICKS(500));
      esp_err_t err1 = read_sht40_raw(&raw_temperature, &raw_humidity);
    
    if (err1 == ESP_OK) {
        ESP_LOGI(TAG, "Temperatura: %.2hu °C", raw_temperature);
        ESP_LOGI(TAG, "Humedad: %.2u %%", raw_humidity);
    } else {
        ESP_LOGE(TAG, "Error al leer el sensor SHT40_");
    }
	convert_raw_sensor_data(raw_temperature,raw_humidity);//no necesario aquí,solo para depuración

	configure_send_trama_lora(raw_temperature, raw_humidity);
		
}


void configure_send_trama_lora(uint16_t raw_temperature, uint16_t raw_humidity) {
	
	// Crear un buffer para almacenar los datos (4 bytes: 2 para temperatura, 2 para humedad)
    uint8_t buf[6];
    //Modo explicito es el que está configurado por defecto
    
 	 lora_enable_crc();               // Habilitar CRC para integridad de datos
   
   //La tasa de corrección de errores por defecto es 4/5 creo (asi que no modifico coding rate)	
  
    // Llenar el buffer con los valores de temperatura y humedad
    buf[0] = MasterNode; //direccion del modulo que recibe
    buf[1] = Node1;      //direccion del módulo que envía
    buf[2] = (raw_temperature >> 8) & 0xFF;  // Byte alto de la temperatura
    buf[3] = raw_temperature & 0xFF;         // Byte bajo de la temperatura
    buf[4] = (raw_humidity >> 8) & 0xFF;   // Byte alto de la humedad
    buf[5] = raw_humidity & 0xFF;          // Byte bajo de la humedad
    
   //esta función escribe los datos en la fifo, pero además establece el RegPayloadLength-> 
   //->se incluye automaticamente en el header
   //Mando los datos raw y los decodifico en el receptor
   lora_send_packet(buf, sizeof(buf));

	//Poner en modo recepcion para esperar el ACK
	lora_receive();
	if(xTimerACK ==NULL)
		{
			set_timer_ACK(); //Activo timer para reequerir el ACK en caso de que no se reciba
			ESP_LOGI(TAG,"Timer activado (reequerimiento ACK-> 10 Seconds).");
		}
	
    // Mensaje de confirmación en el puerto serie
    ESP_LOGI(TAG,"Trama LoRa enviada con exito.");
}
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
